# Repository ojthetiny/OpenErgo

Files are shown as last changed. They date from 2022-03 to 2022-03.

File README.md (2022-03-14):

# OpenErgo
 Open Source Alice Keyboard

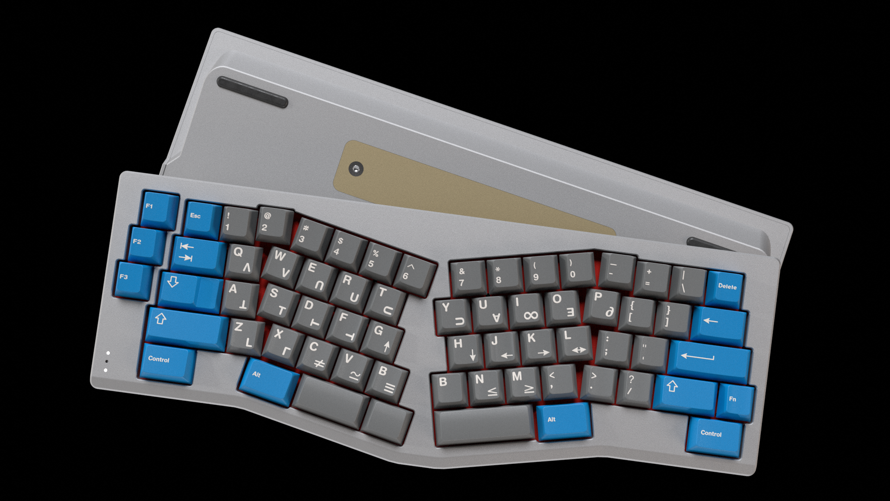
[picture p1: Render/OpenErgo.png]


 Use as a base for your own designs, renders or order as is (read important info at the bottom).

Details:

   - Alice layout
   - Supports OG Alice plate
   - Chonky external weight
   - 7.5 degree typing angle.
   - Flush USB-C connector built into the PCB
   - Skuf feet.
   - 3 Piece construction for no external screws (aside from weight)

Important Info (READ BEFORE ORDERING):

   - I do not offer any sort of warranty for this, nor can I be held liable if something goes wrong.
   - Renders are not fully representative of the final product
   - Please, PLEASE look over the design before you do anything with it, it's possible and very likely that there are some errors, I'm just a human.
   - Theoretically universal Alice pcb support (bottom side USB), though the connector is possibly slightly misaligned, still untested

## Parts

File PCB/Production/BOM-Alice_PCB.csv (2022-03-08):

Comment | Designator | Footprint | LCSC
RB060MM_60TR | D_LDO1 | D_SOD-123 | C115330
PRTR5V0U2X | D_ESD1 | SOT143B | C12333
SM9.0CA | D_PWR1 | D_SOD-123 | C123799
100n | C_VDD1,C_VDD2,C_VDDIO2 | C_0402_1005Metric | C1525
4.7n | C_Shield1 | C_0402_1005Metric | C1538
10u | C_VDDA1 | C_0402_1005Metric | C15525
HRO-TYPE-C-31-M-12 | USB1 | HRO-TYPE-C-31-M-12-Assembly | C165948
SW_SPDT | BOOT1 | SW_SPDT_PCM12 | C221841
4.7u | C_VDD3,C_VDDIO1 | C_0402_1005Metric | C23733
R_Small | R_LED1,R_LED2,R_LED3 | R_0402_1005Metric | C25091
100k | R_LDO1,R_LDO2 | R_0402_1005Metric | C25741
10k | R_BOOT1,R_RGB1 | R_0402_1005Metric | C25744
5k1 | R_USB1,R_USB2 | R_0402_1005Metric | C25905
1M | R_Shield1 | R_0402_1005Metric | C26083
SW_Push | RESET1 | SW_SPST_TL3342 | C318884
MCP1700-3302E_SOT23 | U_Power1 | SOT-23 | C39051
1u | C_LDO1,C_LDO2,C_VDDA2 | C_0402_1005Metric | C52923
D_Small | D_SW_0,D_SW_1,D_SW_2,D_SW_3,D_SW_4,D_SW_5,D_SW_6,D_SW_7,D_SW_8,D_SW_9,D_SW_A1,D_SW_B1,D_SW_B2,D_SW_Back1,D_SW_C1,D_SW_Caps1,D_SW_Comm1,D_SW_D1,D_SW_Dash1,D_SW_Del1,D_SW_Dn1,D_SW_E1,D_SW_Enter1,D_SW_Eql1,D_SW_Esc1,D_SW_F1,D_SW_Fn1,D_SW_G1,D_SW_H1,D_SW_J1,D_SW_K1,D_SW_L1,D_SW_LAlt1,D_SW_LBrc1,D_SW_LCtl1,D_SW_LFn1,D_SW_LSft1,D_SW_LSpc1,D_SW_M1,D_SW_N1,D_SW_O1,D_SW_P1,D_SW_PP2,D_SW_Pipe1,D_SW_Q1,D_SW_Quot1,D_SW_R1,D_SW_RAlt1,D_SW_RBrc1,D_SW_RCtl1,D_SW_RSpc1,D_SW_Rsft1,D_SW_S1,D_SW_Scln1,D_SW_Slsh1,D_SW_Stop1,D_SW_T1,D_SW_Tab1,D_SW_U1,D_SW_Up1,D_SW_V1,D_SW_W1,D_SW_X1,D_SW_Y1,D_SW_Z1 | D_SOD-123 | C64898
STM32F072C8Tx | U_MCU1 | LQFP-48_7x7mm_P0.5mm | C80488
500mA | F1 | Fuse_0805_2012Metric | C883103

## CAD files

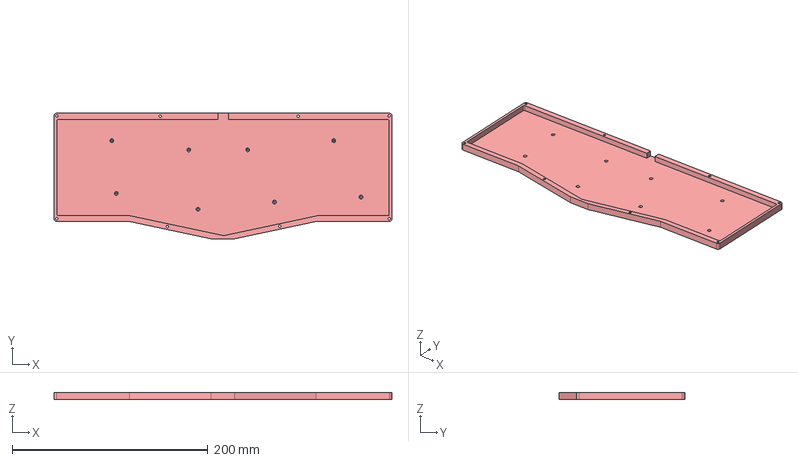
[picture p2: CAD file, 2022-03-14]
Case/Middle.step
345.0 x 128.4 x 7.20 mm

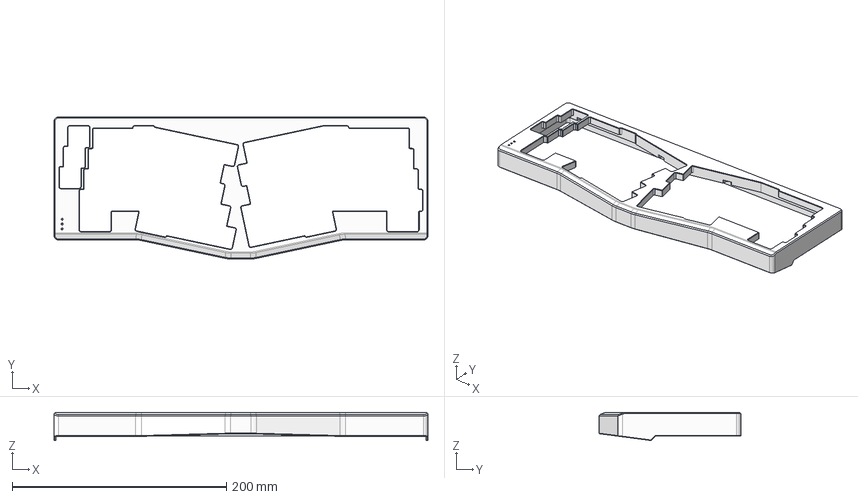
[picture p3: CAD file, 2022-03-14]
Case/Top.step
349.2 x 132.6 x 26.3 mm

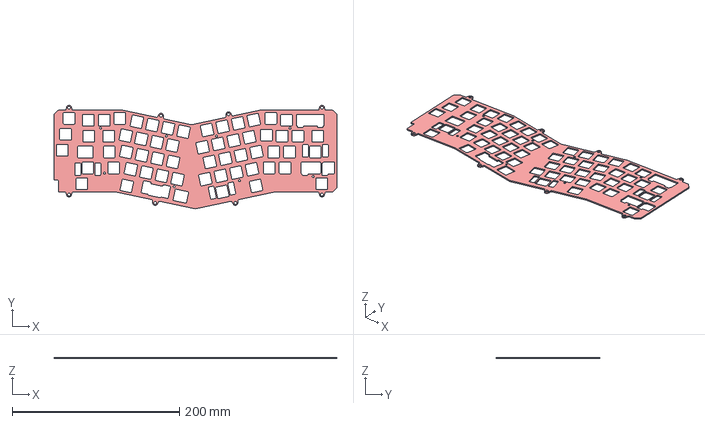
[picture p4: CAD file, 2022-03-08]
Case/Plate.step
338.8 x 123.9 x 1.50 mm

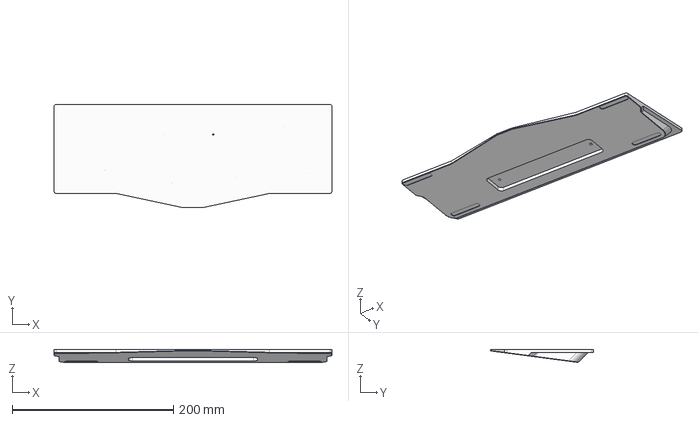
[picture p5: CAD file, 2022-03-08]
Case/Bottom.step
345.0 x 128.4 x 15.9 mm

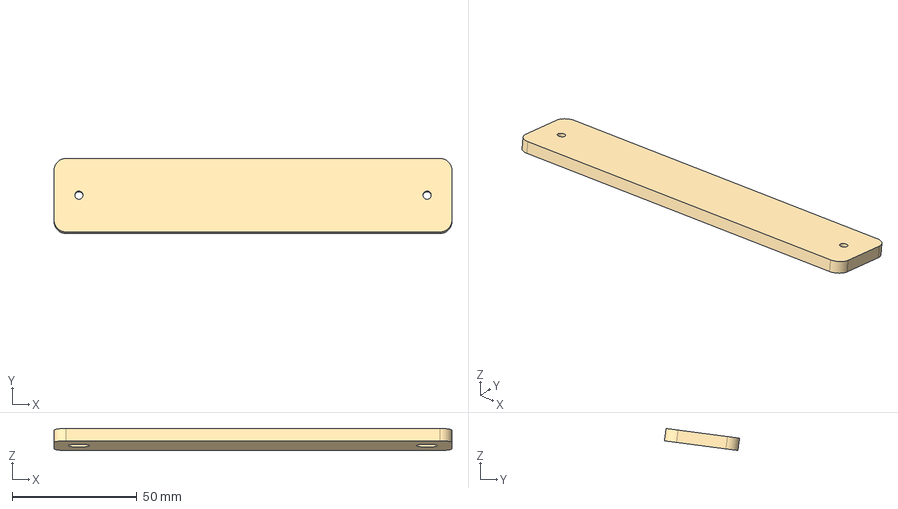
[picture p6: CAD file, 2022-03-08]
Case/Weight.step
159.8 x 30.2 x 8.85 mm

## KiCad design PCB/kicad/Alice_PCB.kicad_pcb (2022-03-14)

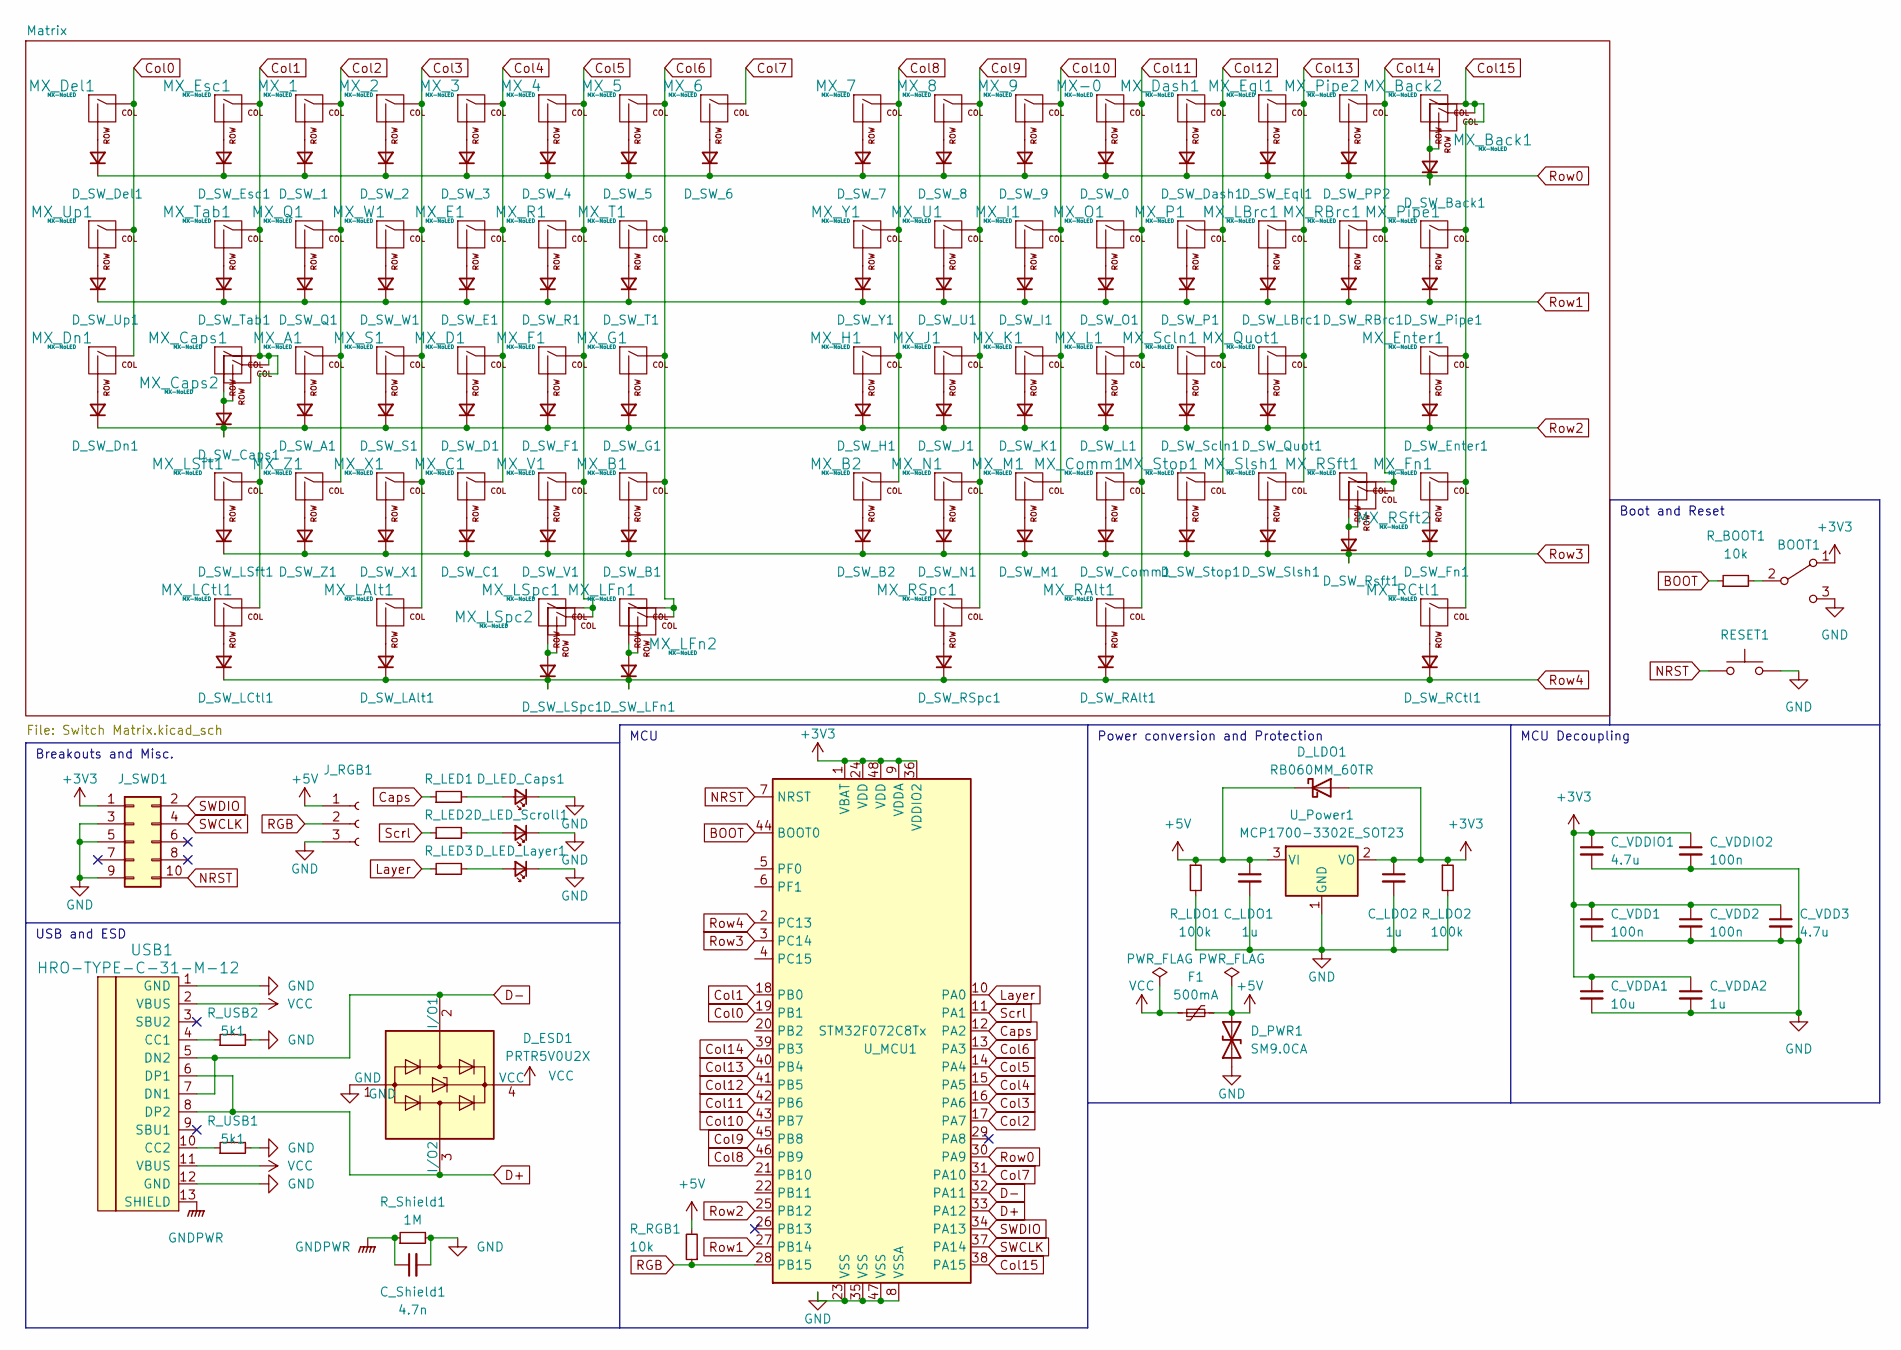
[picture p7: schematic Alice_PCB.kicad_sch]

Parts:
BOOT1: SW_SPDT; SW_SPDT_PCM12
C_LDO1, C_LDO2: 1u; C_0402_1005Metric
C_Shield1: 4.7n; C_0402_1005Metric
C_VDD1, C_VDD2: 100n; C_0402_1005Metric
C_VDD3: 4.7u; C_0402_1005Metric
C_VDDA1: 10u; C_0402_1005Metric
C_VDDA2: 1u; C_0402_1005Metric
C_VDDIO1: 4.7u; C_0402_1005Metric
C_VDDIO2: 100n; C_0402_1005Metric
D_ESD1: PRTR5V0U2X; SOT143B
D_LDO1: RB060MM_60TR; D_SOD-123
D_LED_Caps1: LED_Small; LED_3mm
D_LED_Layer1: LED_Small; LED_3mm
D_LED_Scroll1: LED_Small; LED_3mm
D_PWR1: SM9.0CA; D_SOD-123
D_SW_0, D_SW_1, D_SW_2, D_SW_3, D_SW_4, D_SW_5, D_SW_6, D_SW_7, D_SW_8, D_SW_9: D_Small; D_SOD-123
D_SW_A1: D_Small; D_SOD-123
D_SW_B1, D_SW_B2: D_Small; D_SOD-123
D_SW_Back1: D_Small; D_SOD-123
D_SW_C1: D_Small; D_SOD-123
D_SW_Caps1: D_Small; D_SOD-123
D_SW_Comm1: D_Small; D_SOD-123
D_SW_D1: D_Small; D_SOD-123
D_SW_Dash1: D_Small; D_SOD-123
D_SW_Del1: D_Small; D_SOD-123
D_SW_Dn1: D_Small; D_SOD-123
D_SW_E1: D_Small; D_SOD-123
D_SW_Enter1: D_Small; D_SOD-123
D_SW_Eql1: D_Small; D_SOD-123
D_SW_Esc1: D_Small; D_SOD-123
D_SW_F1: D_Small; D_SOD-123
D_SW_Fn1: D_Small; D_SOD-123
D_SW_G1: D_Small; D_SOD-123
D_SW_H1: D_Small; D_SOD-123
D_SW_I1: D_Small; D_SOD-123
D_SW_J1: D_Small; D_SOD-123
D_SW_K1: D_Small; D_SOD-123
D_SW_L1: D_Small; D_SOD-123
D_SW_LAlt1: D_Small; D_SOD-123
D_SW_LBrc1: D_Small; D_SOD-123
D_SW_LCtl1: D_Small; D_SOD-123
D_SW_LFn1: D_Small; D_SOD-123
D_SW_LSft1: D_Small; D_SOD-123
D_SW_LSpc1: D_Small; D_SOD-123
D_SW_M1: D_Small; D_SOD-123
D_SW_N1: D_Small; D_SOD-123
D_SW_O1: D_Small; D_SOD-123
D_SW_P1: D_Small; D_SOD-123
D_SW_PP2: D_Small; D_SOD-123
D_SW_Pipe1: D_Small; D_SOD-123
D_SW_Q1: D_Small; D_SOD-123
D_SW_Quot1: D_Small; D_SOD-123
D_SW_R1: D_Small; D_SOD-123
D_SW_RAlt1: D_Small; D_SOD-123
D_SW_RBrc1: D_Small; D_SOD-123
D_SW_RCtl1: D_Small; D_SOD-123
D_SW_RSpc1: D_Small; D_SOD-123
D_SW_Rsft1: D_Small; D_SOD-123
D_SW_S1: D_Small; D_SOD-123
D_SW_Scln1: D_Small; D_SOD-123
D_SW_Slsh1: D_Small; D_SOD-123
D_SW_Stop1: D_Small; D_SOD-123
D_SW_T1: D_Small; D_SOD-123
D_SW_Tab1: D_Small; D_SOD-123
D_SW_U1: D_Small; D_SOD-123
D_SW_Up1: D_Small; D_SOD-123
D_SW_V1: D_Small; D_SOD-123
D_SW_W1: D_Small; D_SOD-123
D_SW_X1: D_Small; D_SOD-123
D_SW_Y1: D_Small; D_SOD-123
D_SW_Z1: D_Small; D_SOD-123
F1: 500mA; Fuse_0805_2012Metric
J_RGB1: RGB; PinHeader_1x03_P2.54mm_Vertical
J_SWD1: SWD; PinHeader_2x05_P2.54mm_Vertical
MX-0: MX-NoLED; MX_1u_NoLED
MX_1, MX_2, MX_3, MX_4, MX_5, MX_6, MX_7, MX_8, MX_9: MX-NoLED; MX_1u_NoLED
MX_A1: MX-NoLED; MX_1u_NoLED
MX_B1, MX_B2: MX-NoLED; MX_1u_NoLED
MX_Back1: MX-NoLED; MX_2u_NoLED
MX_Back2: MX-NoLED; MX_1u_NoLED
MX_C1: MX-NoLED; MX_1u_NoLED
MX_Caps1: MX-NoLED; MX_1.75u_NoLED
MX_Caps2: MX-NoLED; MX_1.25u_NoLED
MX_Comm1: MX-NoLED; MX_1u_NoLED
MX_D1: MX-NoLED; MX_1u_NoLED
MX_Dash1: MX-NoLED; MX_1u_NoLED
MX_Del1: MX-NoLED; MX_1u_NoLED
MX_Dn1: MX-NoLED; MX_1u_NoLED
MX_E1: MX-NoLED; MX_1u_NoLED
MX_Enter1: MX-NoLED; MX_2.25u_ReversedStabilizers_NoLED
MX_Eql1: MX-NoLED; MX_1u_NoLED
MX_Esc1: MX-NoLED; MX_1u_NoLED
MX_F1: MX-NoLED; MX_1u_NoLED
MX_Fn1: MX-NoLED; MX_1u_NoLED
MX_G1: MX-NoLED; MX_1u_NoLED
MX_H1: MX-NoLED; MX_1u_NoLED
MX_I1: MX-NoLED; MX_1u_NoLED
MX_J1: MX-NoLED; MX_1u_NoLED
MX_K1: MX-NoLED; MX_1u_NoLED
MX_L1: MX-NoLED; MX_1u_NoLED
MX_LAlt1: MX-NoLED; MX_1.5u_NoLED
MX_LBrc1: MX-NoLED; MX_1u_NoLED
MX_LCtl1: MX-NoLED; MX_1.5u_NoLED
MX_LFn1: MX-NoLED; MX_1u_NoLED
MX_LFn2: MX-NoLED; MX_1.25u_NoLED
MX_LSft1: MX-NoLED; MX_2.25u_NoLED
MX_LSpc1: MX-NoLED; MX_2.25u_ReversedStabilizers_NoLED
MX_LSpc2: MX-NoLED; MX_2u_ReversedStabilizers_NoLED
MX_M1: MX-NoLED; MX_1u_NoLED
MX_N1: MX-NoLED; MX_1u_NoLED
MX_O1: MX-NoLED; MX_1u_NoLED
MX_P1: MX-NoLED; MX_1u_NoLED
MX_Pipe1: MX-NoLED; MX_1.5u_NoLED
MX_Pipe2: MX-NoLED; MX_1u_NoLED
MX_Q1: MX-NoLED; MX_1u_NoLED
MX_Quot1: MX-NoLED; MX_1u_NoLED
MX_R1: MX-NoLED; MX_1u_NoLED
MX_RAlt1: MX-NoLED; MX_1.5u_NoLED
MX_RBrc1: MX-NoLED; MX_1u_NoLED
MX_RCtl1: MX-NoLED; MX_1.5u_NoLED
MX_RSft1: MX-NoLED; MX_2.75u_NoLED
MX_RSft2: MX-NoLED; MX_1.75u_NoLED
MX_RSpc1: MX-NoLED; MX_2.75u_ReversedStabilizers_NoLED
MX_S1: MX-NoLED; MX_1u_NoLED
MX_Scln1: MX-NoLED; MX_1u_NoLED
MX_Slsh1: MX-NoLED; MX_1u_NoLED
MX_Stop1: MX-NoLED; MX_1u_NoLED
MX_T1: MX-NoLED; MX_1u_NoLED
MX_Tab1: MX-NoLED; MX_1.5u_NoLED
MX_U1: MX-NoLED; MX_1u_NoLED
MX_Up1: MX-NoLED; MX_1u_NoLED
MX_V1: MX-NoLED; MX_1u_NoLED
MX_W1: MX-NoLED; MX_1u_NoLED
MX_X1: MX-NoLED; MX_1u_NoLED
MX_Y1: MX-NoLED; MX_1u_NoLED
MX_Z1: MX-NoLED; MX_1u_NoLED
RESET1: SW_Push; SW_SPST_TL3342
R_BOOT1: 10k; R_0402_1005Metric
R_LDO1, R_LDO2: 100k; R_0402_1005Metric
R_LED1, R_LED2, R_LED3: R_Small; R_0402_1005Metric
R_RGB1: 10k; R_0402_1005Metric
R_Shield1: 1M; R_0402_1005Metric
R_USB1, R_USB2: 5k1; R_0402_1005Metric
USB1: HRO-TYPE-C-31-M-12; HRO-TYPE-C-31-M-12-Assembly
U_MCU1: STM32F072C8Tx; LQFP-48_7x7mm_P0.5mm
U_Power1: MCP1700-3302E_SOT23; SOT-23

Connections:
+3V3: BOOT1.1 (A), C_LDO2.1, C_VDD1.1, C_VDD2.1, C_VDD3.1, C_VDDA1.1, C_VDDA2.1, C_VDDIO1.1, C_VDDIO2.1, D_LDO1.2 (A), J_SWD1.1, R_LDO2.1, U_MCU1.1 (VBAT), U_MCU1.9 (VDDA), U_MCU1.24 (VDD), U_MCU1.36 (VDDIO2), U_MCU1.48 (VDD), U_Power1.2 (VO)
+5V: C_LDO1.1, D_LDO1.1 (K), D_PWR1.2 (A2), F1.2, J_RGB1.1, R_LDO1.1, R_RGB1.2, U_Power1.3 (VI)
BOOT: R_BOOT1.1, U_MCU1.44 (BOOT0)
Caps: R_LED1.1, U_MCU1.12 (PA2)
Col0: MX_Del1.1 (COL), MX_Dn1.1 (COL), MX_Up1.1 (COL), U_MCU1.19 (PB1)
Col1: MX_Caps1.1 (COL), MX_Caps2.1 (COL), MX_Esc1.1 (COL), MX_LCtl1.1 (COL), MX_LSft1.1 (COL), MX_Tab1.1 (COL), U_MCU1.18 (PB0)
Col2: MX_1.1 (COL), MX_A1.1 (COL), MX_Q1.1 (COL), MX_Z1.1 (COL), U_MCU1.17 (PA7)
Col3: MX_2.1 (COL), MX_LAlt1.1 (COL), MX_S1.1 (COL), MX_W1.1 (COL), MX_X1.1 (COL), U_MCU1.16 (PA6)
Col4: MX_3.1 (COL), MX_C1.1 (COL), MX_D1.1 (COL), MX_E1.1 (COL), U_MCU1.15 (PA5)
Col5: MX_4.1 (COL), MX_F1.1 (COL), MX_LSpc1.1 (COL), MX_LSpc2.1 (COL), MX_R1.1 (COL), MX_V1.1 (COL), U_MCU1.14 (PA4)
Col6: MX_5.1 (COL), MX_B1.1 (COL), MX_G1.1 (COL), MX_LFn1.1 (COL), MX_LFn2.1 (COL), MX_T1.1 (COL), U_MCU1.13 (PA3)
Col7: MX_6.1 (COL), U_MCU1.31 (PA10)
Col8: MX_7.1 (COL), MX_B2.1 (COL), MX_H1.1 (COL), MX_Y1.1 (COL), U_MCU1.46 (PB9)
Col9: MX_8.1 (COL), MX_J1.1 (COL), MX_N1.1 (COL), MX_RSpc1.1 (COL), MX_U1.1 (COL), U_MCU1.45 (PB8)
Col10: MX_9.1 (COL), MX_I1.1 (COL), MX_K1.1 (COL), MX_M1.1 (COL), U_MCU1.43 (PB7)
Col11: MX-0.1 (COL), MX_Comm1.1 (COL), MX_L1.1 (COL), MX_O1.1 (COL), MX_RAlt1.1 (COL), U_MCU1.42 (PB6)
Col12: MX_Dash1.1 (COL), MX_P1.1 (COL), MX_Scln1.1 (COL), MX_Stop1.1 (COL), U_MCU1.41 (PB5)
Col13: MX_Eql1.1 (COL), MX_LBrc1.1 (COL), MX_Quot1.1 (COL), MX_Slsh1.1 (COL), U_MCU1.40 (PB4)
Col14: MX_Pipe2.1 (COL), MX_RBrc1.1 (COL), MX_RSft1.1 (COL), MX_RSft2.1 (COL), U_MCU1.39 (PB3)
Col15: MX_Back1.1 (COL), MX_Back2.1 (COL), MX_Enter1.1 (COL), MX_Fn1.1 (COL), MX_Pipe1.1 (COL), MX_RCtl1.1 (COL), U_MCU1.38 (PA15)
D+: D_ESD1.3 (I/O2), USB1.6 (DP1), USB1.8 (DP2), U_MCU1.33 (PA12)
D-: D_ESD1.2 (I/O1), USB1.5 (DN2), USB1.7 (DN1), U_MCU1.32 (PA11)
GND: BOOT1.3 (C), C_LDO1.2, C_LDO2.2, C_Shield1.2, C_VDD1.2, C_VDD2.2, C_VDD3.2, C_VDDA1.2, C_VDDA2.2, C_VDDIO1.2, C_VDDIO2.2, D_ESD1.1 (GND), D_LED_Caps1.1 (K), D_LED_Layer1.1 (K), D_LED_Scroll1.1 (K), D_PWR1.1 (A1), J_RGB1.3, J_SWD1.3, J_SWD1.5, J_SWD1.9, RESET1.2, R_LDO1.2, R_LDO2.2, R_Shield1.2, R_USB1.2, R_USB2.2, USB1.1 (GND), USB1.12 (GND), U_MCU1.8 (VSSA), U_MCU1.23 (VSS), U_MCU1.35 (VSS), U_MCU1.47 (VSS), U_Power1.1 (GND)
GNDPWR: C_Shield1.1, R_Shield1.1, USB1.13 (SHIELD)
Layer: R_LED3.1, U_MCU1.10 (PA0)
NRST: J_SWD1.10, RESET1.1, U_MCU1.7 (NRST)
unnamed: D_LED_Layer1.2 (A), R_LED3.2
unnamed: D_SW_Back1.2 (A), MX_Back1.2 (ROW), MX_Back2.2 (ROW)
unnamed: D_SW_E1.2 (A), MX_E1.2 (ROW)
unnamed 29: D_SW_I1.2 (A), MX_I1.2 (ROW); also elsewhere on the board
unnamed: D_SW_LBrc1.2 (A), MX_LBrc1.2 (ROW)
unnamed: D_SW_O1.2 (A), MX_O1.2 (ROW)
unnamed: D_SW_P1.2 (A), MX_P1.2 (ROW)
unnamed: D_SW_Pipe1.2 (A), MX_Pipe1.2 (ROW)
unnamed: D_SW_Q1.2 (A), MX_Q1.2 (ROW)
unnamed: D_SW_R1.2 (A), MX_R1.2 (ROW)
unnamed: D_SW_RBrc1.2 (A), MX_RBrc1.2 (ROW)
unnamed: D_SW_T1.2 (A), MX_T1.2 (ROW)
unnamed: D_SW_Tab1.2 (A), MX_Tab1.2 (ROW)
unnamed: D_SW_U1.2 (A), MX_U1.2 (ROW)
unnamed: D_SW_Up1.2 (A), MX_Up1.2 (ROW)
unnamed: D_SW_W1.2 (A), MX_W1.2 (ROW)
unnamed: D_SW_Y1.2 (A), MX_Y1.2 (ROW)
unnamed: D_SW_0.2 (A), MX-0.2 (ROW)
unnamed: D_SW_1.2 (A), MX_1.2 (ROW)
unnamed: D_SW_2.2 (A), MX_2.2 (ROW)
unnamed: D_SW_3.2 (A), MX_3.2 (ROW)
unnamed: D_SW_4.2 (A), MX_4.2 (ROW)
unnamed: D_SW_5.2 (A), MX_5.2 (ROW)
unnamed: D_SW_6.2 (A), MX_6.2 (ROW)
unnamed: D_SW_7.2 (A), MX_7.2 (ROW)
unnamed: D_SW_8.2 (A), MX_8.2 (ROW)
unnamed: D_SW_9.2 (A), MX_9.2 (ROW)
unnamed: D_SW_A1.2 (A), MX_A1.2 (ROW)
unnamed: D_SW_B1.2 (A), MX_B1.2 (ROW)
unnamed: D_SW_B2.2 (A), MX_B2.2 (ROW)
unnamed: D_SW_C1.2 (A), MX_C1.2 (ROW)
unnamed: D_SW_Caps1.2 (A), MX_Caps1.2 (ROW), MX_Caps2.2 (ROW)
unnamed: D_SW_Comm1.2 (A), MX_Comm1.2 (ROW)
unnamed: D_SW_D1.2 (A), MX_D1.2 (ROW)
unnamed: D_SW_Dash1.2 (A), MX_Dash1.2 (ROW)
unnamed: D_SW_Del1.2 (A), MX_Del1.2 (ROW)
unnamed: D_SW_Dn1.2 (A), MX_Dn1.2 (ROW)
unnamed: D_SW_Enter1.2 (A), MX_Enter1.2 (ROW)
unnamed: D_SW_Eql1.2 (A), MX_Eql1.2 (ROW)
unnamed: D_SW_Esc1.2 (A), MX_Esc1.2 (ROW)
unnamed: D_SW_F1.2 (A), MX_F1.2 (ROW)
unnamed: D_SW_Fn1.2 (A), MX_Fn1.2 (ROW)
unnamed: D_SW_G1.2 (A), MX_G1.2 (ROW)
unnamed: D_SW_H1.2 (A), MX_H1.2 (ROW)
unnamed: D_SW_J1.2 (A), MX_J1.2 (ROW)
unnamed: D_SW_K1.2 (A), MX_K1.2 (ROW)
unnamed: D_SW_L1.2 (A), MX_L1.2 (ROW)
unnamed: D_SW_LAlt1.2 (A), MX_LAlt1.2 (ROW)
unnamed: D_SW_LCtl1.2 (A), MX_LCtl1.2 (ROW)
unnamed: D_SW_LFn1.2 (A), MX_LFn1.2 (ROW), MX_LFn2.2 (ROW)
unnamed: D_SW_LSft1.2 (A), MX_LSft1.2 (ROW)
unnamed: D_SW_LSpc1.2 (A), MX_LSpc1.2 (ROW), MX_LSpc2.2 (ROW)
unnamed: D_SW_M1.2 (A), MX_M1.2 (ROW)
unnamed: D_SW_N1.2 (A), MX_N1.2 (ROW)
unnamed: D_SW_PP2.2 (A), MX_Pipe2.2 (ROW)
unnamed: D_SW_Quot1.2 (A), MX_Quot1.2 (ROW)
unnamed: D_SW_RAlt1.2 (A), MX_RAlt1.2 (ROW)
unnamed: D_SW_RCtl1.2 (A), MX_RCtl1.2 (ROW)
unnamed: D_SW_Rsft1.2 (A), MX_RSft1.2 (ROW), MX_RSft2.2 (ROW)
unnamed: D_SW_RSpc1.2 (A), MX_RSpc1.2 (ROW)
unnamed: D_SW_S1.2 (A), MX_S1.2 (ROW)
unnamed: D_SW_Scln1.2 (A), MX_Scln1.2 (ROW)
unnamed: D_SW_Slsh1.2 (A), MX_Slsh1.2 (ROW)
unnamed: D_SW_Stop1.2 (A), MX_Stop1.2 (ROW)
unnamed: D_SW_V1.2 (A), MX_V1.2 (ROW)
unnamed: D_SW_X1.2 (A), MX_X1.2 (ROW)
unnamed: D_SW_Z1.2 (A), MX_Z1.2 (ROW)
unnamed: BOOT1.2 (B), R_BOOT1.2
unnamed: D_LED_Caps1.2 (A), R_LED1.2
unnamed: D_LED_Scroll1.2 (A), R_LED2.2
unnamed: R_USB2.1, USB1.4 (CC1)
unnamed: R_USB1.1, USB1.10 (CC2)
RGB: J_RGB1.2, R_RGB1.1, U_MCU1.28 (PB15)
Row0: D_SW_0.1 (K), D_SW_1.1 (K), D_SW_2.1 (K), D_SW_3.1 (K), D_SW_4.1 (K), D_SW_5.1 (K), D_SW_6.1 (K), D_SW_7.1 (K), D_SW_8.1 (K), D_SW_9.1 (K), D_SW_Back1.1 (K), D_SW_Dash1.1 (K), D_SW_Del1.1 (K), D_SW_Eql1.1 (K), D_SW_Esc1.1 (K), D_SW_PP2.1 (K), U_MCU1.30 (PA9)
Row1: D_SW_E1.1 (K), D_SW_I1.1 (K), D_SW_LBrc1.1 (K), D_SW_O1.1 (K), D_SW_P1.1 (K), D_SW_Pipe1.1 (K), D_SW_Q1.1 (K), D_SW_R1.1 (K), D_SW_RBrc1.1 (K), D_SW_T1.1 (K), D_SW_Tab1.1 (K), D_SW_U1.1 (K), D_SW_Up1.1 (K), D_SW_W1.1 (K), D_SW_Y1.1 (K), U_MCU1.27 (PB14); also elsewhere on the board
Row2: D_SW_A1.1 (K), D_SW_Caps1.1 (K), D_SW_D1.1 (K), D_SW_Dn1.1 (K), D_SW_Enter1.1 (K), D_SW_F1.1 (K), D_SW_G1.1 (K), D_SW_H1.1 (K), D_SW_J1.1 (K), D_SW_K1.1 (K), D_SW_L1.1 (K), D_SW_Quot1.1 (K), D_SW_S1.1 (K), D_SW_Scln1.1 (K), U_MCU1.25 (PB12)
Row3: D_SW_B1.1 (K), D_SW_B2.1 (K), D_SW_C1.1 (K), D_SW_Comm1.1 (K), D_SW_Fn1.1 (K), D_SW_LSft1.1 (K), D_SW_M1.1 (K), D_SW_N1.1 (K), D_SW_Rsft1.1 (K), D_SW_Slsh1.1 (K), D_SW_Stop1.1 (K), D_SW_V1.1 (K), D_SW_X1.1 (K), D_SW_Z1.1 (K), U_MCU1.3 (PC14)
Row4: D_SW_LAlt1.1 (K), D_SW_LCtl1.1 (K), D_SW_LFn1.1 (K), D_SW_LSpc1.1 (K), D_SW_RAlt1.1 (K), D_SW_RCtl1.1 (K), D_SW_RSpc1.1 (K), U_MCU1.2 (PC13)
SWCLK: J_SWD1.4, U_MCU1.37 (PA14)
SWDIO: J_SWD1.2, U_MCU1.34 (PA13)
Scrl: R_LED2.1, U_MCU1.11 (PA1)
VCC: D_ESD1.4 (VCC), F1.1, USB1.2 (VBUS), USB1.11 (VBUS)

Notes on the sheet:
USB and ESD
Power conversion and Protection
MCU
Boot and Reset
MCU Decoupling
Breakouts and Misc.

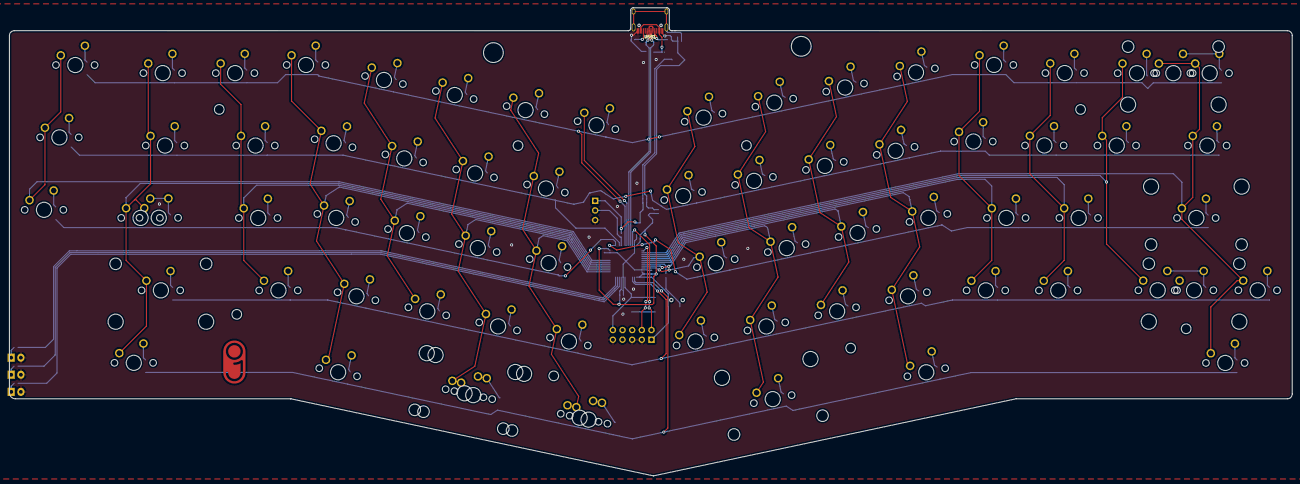
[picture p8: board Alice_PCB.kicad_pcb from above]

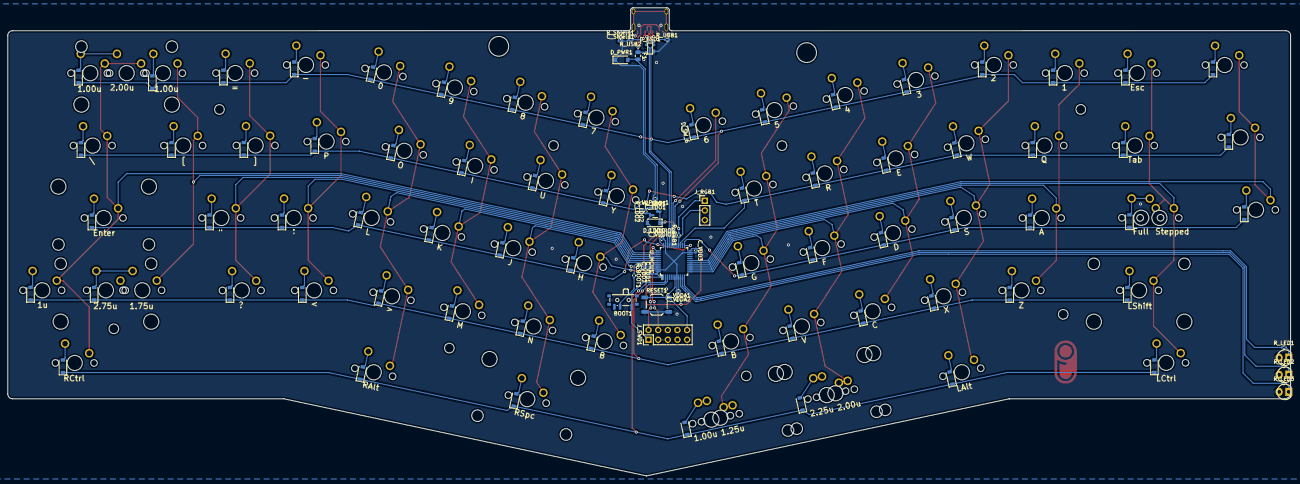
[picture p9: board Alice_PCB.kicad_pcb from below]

Board: 2 copper layers, 337.5 x 123.1 mm, 171 parts (99 on the bottom side), 108 nets.

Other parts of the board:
D_SW_Ie: D_Small; D_SOD-123

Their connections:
unnamed 29: D_SW_Ie.2 (A); also elsewhere on the board
Row1: D_SW_Ie.1 (K); also elsewhere on the board

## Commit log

2022-03-08 Fixed couple typo's
2022-03-14 Fixed USB port positioning
    fixed the USB port position to fit other alice style cases, as well as changed USB from bottom to top mount
    [Alice_PCB-B_Cu.gbl, Alice_PCB-B_Mask.gbs, Alice_PCB-B_Paste.gbp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]
